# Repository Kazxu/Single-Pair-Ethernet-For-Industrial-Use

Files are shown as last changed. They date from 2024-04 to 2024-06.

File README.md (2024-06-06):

# Single Pair Ethernet For Industrial Use

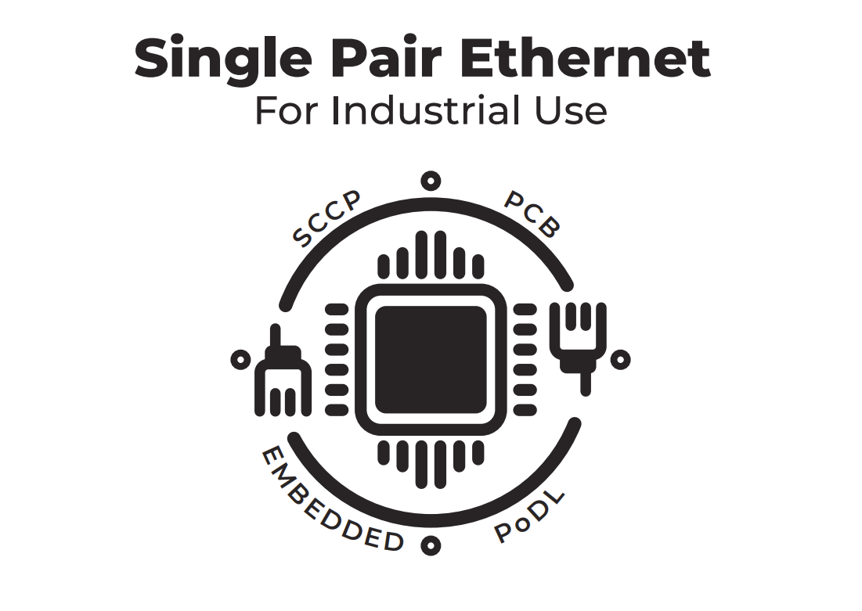
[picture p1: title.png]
ADIN1110_Title


## KICAD
KICAD PCB design files for the LTC4296-1 PSE prototype and LTC9111 PD prototype.

## SCCP 

SCCP_2 uses SPI to communicate with the LTC4296-1 prototype. 

See program print for features. 

SCCP classification between LTC4296-1 and LTC9111 can be performed as well.

## ADIN1110 - Development with STM32Cube IDE.

MCU Firmware : STM32L4xx - https://github.com/STMicroelectronics/STM32CubeL4 

LL DRIVERS : ADIN1110 Support files by Analog Devices.

TCP/IP : LWIP 2.1.2 & Callback API from LWIP. 

Serial Monitor : USART.c & USART.h, huart1.Init.BaudRate = 115200

ADC : INIT in Main.c & stm32l4xx_hal_msp.c

Client-side GUI CONCEPT PROTOTYPE - Python, Added as placeholder for showcase.

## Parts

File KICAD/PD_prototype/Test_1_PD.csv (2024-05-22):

# | Reference | Qty | Value | Footprint | Link Norge | Link JLCPCB | Link Andre steder
1 | C1 | 1 | 150nF | Capacitor_SMD:C_1206_3216Metric | https://no.farnell.com/tdk/cga5l2x7r2a154k160aa/cap-0-15-f-100v-10-x7r-1206/dp/2211081
2 | C2, C3 | 2 | 47nF | Capacitor_SMD:C_0805_2012Metric | https://no.farnell.com/kemet/c0805c473k1ractu/cap-0-047-f-100v-10-x7r-0805/dp/1907057
3 | CBULK1 | 1 | 47uF | 6.3x5.8 SMD tube | https://no.farnell.com/panasonic/eeefk1v470p/cap-47-f-35v-radial-smd-reel/dp/2254455
4 | CGATE1 | 1 | 22nF | Capacitor_SMD:C_0805_2012Metric | https://no.farnell.com/kemet/c0805x223k1ractu/cap-0-022-f-100v-10-x7r-0805/dp/1414043
5 | CSTBY1 | 1 | 2.2uF | Capacitor_SMD:C_0805_2012Metric | https://no.farnell.com/kemet/c0805c225k9ractu/cap-2-2-f-6-3v-10-x7r-0805/dp/2896867
6 | D1, D2 | 2 | PMEG10020AELR | Diode_SMD:Nexperia_CFP3_SOD-123W | https://no.farnell.com/nexperia/pmeg10020aelrx/schottky-rect-2a-100v-smd/dp/2498546?st=PMEG10020AELRX
7 | D3 | 1 | PTVS58VP1UTP | Diode_SMD:D_SOD-128 | https://no.farnell.com/nexperia/ptvs58vp1up-115/tvs-diodes/dp/4270914?st=PTVS58VP1UP,115
8 | IC1 | 1 | LTC9111RDE#PBF | KiCad:SON50P300X400X80-13N-D |  |  | https://no.mouser.com/ProductDetail/Analog-Devices/LTC9111RDEPBF?qs=rQFj71Wb1eUvOGbK5XL1vA%3D%3D
9 | J1 | 1 | Conn_01x04_Pin | Connector_PinHeader_2.54mm:PinHeader_1x04_P2.54mm_Vertical
10 | J2, J3 | 2 | Conn_01x06_Pin | Connector_PinHeader_2.54mm:PinHeader_1x06_P2.54mm_Vertical
11 | L2 | 1 | MSD7342-683MLC | footprints:MSD7342_COC | https://no.mouser.com/ProductDetail/Coilcraft/MSD7342-683MLC?qs=zCSbvcPd3pYlH%252BpyLo9nbw%3D%3D
12 | Q1 | 1 | PSMN075-100MSEX | footprints2:LFPAK33_SOT1210_NEX | https://no.farnell.com/nexperia/psmn075-100msex/mosfet-n-ch-100v-18a-lfpak33/dp/3440099?st=PSMN075-100MSEX
13 | Q2, Q3 | 2 | BSS123 | Package_TO_SOT_SMD:SOT-23 | https://no.farnell.com/onsemi/bss123/mosfet-n-100v-sot-23/dp/9845321?st=BSS123
14 | Q4, Q5 | 2 | BUK9M120-100EX | Package_TO_SOT_SMD:LFPAK33 | https://no.farnell.com/nexperia/buk9m120-100ex/mosfet-n-ch-aec-q101-11-5a-100v/dp/2760379?st=BUK9M120-100EX
15 | R1 | 1 | 40, 1/4 | Resistor_SMD:R_1206_3225Metric | https://no.farnell.com/yageo/rc1206fr-0743rl/res-43r-1-0-25w-1206-thick-film/dp/3496243
16 | R2 | 1 | 100 | Resistor_SMD:R_1206_3216Metric | https://no.farnell.com/vishay/crcw1206100rfkea/res-100r-1-0-25w-1206-thick-film/dp/1469977
17 | R3, R4, RBULK1 | 3 | 3.3, 1/4 | Resistor_SMD:R_1206_3216Metric | https://no.farnell.com/tt-electronics-welwyn/asc1206-3r3ft5/res-3r3-1-0-25w-1206-thick-film/dp/2078985
18 | RGATE1 | 1 | 10k | Resistor_SMD:R_1206_3216Metric | https://no.farnell.com/yageo/rc1206jr-0710kl/res-10k-5-0-25w-1206-thick-film/dp/9240640

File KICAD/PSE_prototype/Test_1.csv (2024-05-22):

# | Reference | Qty | Value | Footprint | DNP
1 | C1 | 1 | 1uF | Capacitor_SMD:C_0805_2012Metric | x
2 | C2 | 1 | 1nF | Capacitor_SMD:C_0805_2012Metric | x
3 | C3 | 1 | 0.1uF | Capacitor_SMD:C_0805_2012Metric | x
4 | C4 | 1 | 2.2u | Capacitor_SMD:C_0805_2012Metric | x
5 | C5, C7 | 2 | 2.2n | Capacitor_SMD:C_0805_2012Metric | x
6 | C6 | 1 | 0.47u | Capacitor_SMD:C_1206_3216Metric | x | 7
7 | D1 | 1 | SMAJ33A | Diode_SMD:D_SMA | x | 8
8 | J1 | 1 | Conn_01x04_Pin | Connector_PinHeader_2.54mm:PinHeader_1x04_P2.54mm_Vertical
9 | J2, J3 | 2 | Conn_01x02_Pin | Connector_PinHeader_2.54mm:PinHeader_1x02_P2.54mm_Vertical
10 | J4, J5, J6 | 3 | Conn_01x01_Pin | Connector_PinHeader_2.54mm:PinHeader_1x01_P2.54mm_Vertical
11 | J105, J106 | 2 | Conn_01x06_Pin | Connector_PinHeader_2.54mm:PinHeader_1x06_P2.54mm_Vertical
12 | JP1, JP2, JP3 | 3 | Jumper_3_Open | Connector_PinHeader_2.54mm:PinHeader_1x03_P2.54mm_Vertical
13 | L1 | 1 | MSD7342-683MLC | footprints:MSD7342_COC | x | 9
14 | Q1 | 1 | BUK7M45-40EX | Package_TO_SOT_SMD:LFPAK33 | x
15 | Q2, Q3 | 2 | BSS123 | Package_TO_SOT_SMD:SOT-23 | x
16 | Q4 | 1 | MMBTA06 | Package_TO_SOT_SMD:SOT-23 | x | 13
17 | R1 | 1 | 0.62 | Resistor_SMD:R_1206_3216Metric | x
18 | R2 | 1 | 50 | Resistor_SMD:R_0805_2012Metric | x
19 | R3 | 1 | 20 | Resistor_SMD:R_0805_2012Metric | x
20 | R4 | 1 | 10k | Resistor_SMD:R_0805_2012Metric | x
21 | R5, R8, R11 | 3 | 5k | Resistor_SMD:R_0805_2012Metric | x
22 | R6, R9 | 2 | 5 | Resistor_SMD:R_0805_2012Metric | x
23 | R7 | 1 | 24.3k | Resistor_SMD:R_0805_2012Metric | x
24 | R10 | 1 | 50k | Resistor_SMD:R_0805_2012Metric | x | 24
25 | U1 | 1 | ~ | Package_DFN_QFN:QFN-48-1EP_7x7mm_P0.5mm_EP5.3x5.3mm | x
26 | U2 | 1 | MOUDLE-SEEEDUINO-XIAO | XIAO_PCB:MOUDLE14P-2.54-21X17.8MM | x | 26

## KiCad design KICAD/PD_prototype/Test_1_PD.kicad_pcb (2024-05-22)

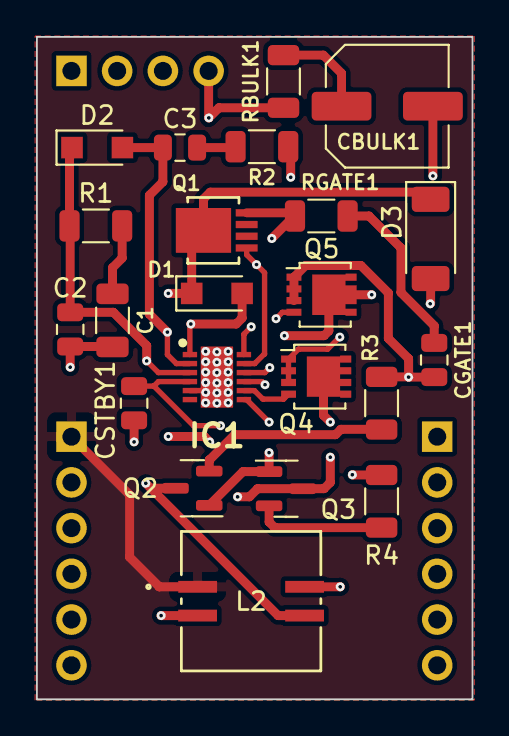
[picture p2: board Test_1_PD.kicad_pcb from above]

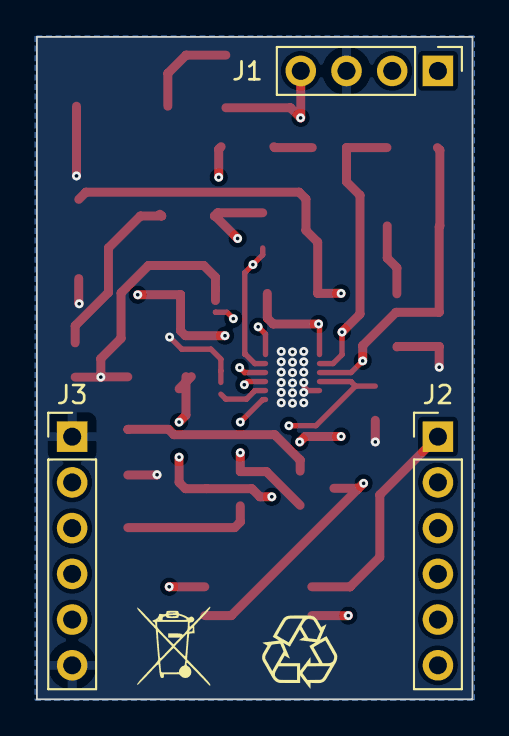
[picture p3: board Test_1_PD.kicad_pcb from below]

Board: 4 copper layers, 24.2 x 36.8 mm, 25 parts (3 on the bottom side), 18 nets.

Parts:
C1: 150nF; C_1206_3216Metric
C2, C3: 47nF; C_0805_2012Metric
CBULK1: 47uF; C_Elec_6.3x7.7
CGATE1: 22nF; C_0805_2012Metric
CSTBY1: 2.2uF; C_0805_2012Metric
D1, D2: PMEG10020AELR; Nexperia_CFP3_SOD-123W
D3: D_Zener; D_SOD-128
IC1: LTC9111RDE#PBF; SON50P300X400X80-13N-D
J1: Conn_01x04_Pin; PinHeader_1x04_P2.54mm_Vertical
J2, J3: Conn_01x06_Pin; PinHeader_1x06_P2.54mm_Vertical
L2: MSD7342-683MLC; MSD7342_COC
Q1: PSMN075-100MSEX; LFPAK33_SOT1210_NEX
Q2, Q3: BSS123; SOT-23
Q4, Q5: BUK9M120-100EX; LFPAK33
R1: 40, 1/4; R_1206_3216Metric
R2: 100; R_1206_3216Metric
R3, R4: 3.3, 1/4; R_1206_3216Metric
RBULK1: 3.3, 1/4; R_1206_3216Metric
RGATE1: 10k; R_1206_3216Metric

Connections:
/PODL+: J2.1, L2.1
/PODL-: J2.6, L2.4
GND: C1.2, C2.2, CBULK1.2, CGATE1.2, CSTBY1.2, D3.2 (A), IC1.5 (CLASSV), IC1.13 (GND), J1.3, J3.1, J3.6, Q4.1 (S), Q4.2 (S), Q4.3 (S), Q5.1 (S), Q5.2 (S), Q5.3 (S), R3.2, R4.2
unnamed: C1.1, R1.2
unnamed: C3.1, R2.2
unnamed: CBULK1.1, RBULK1.2
unnamed: CGATE1.1, RGATE1.2
unnamed: D1.2 (A), IC1.1 (SNS1), L2.3, Q2.3 (D), Q5.5 (D), R2.1
unnamed: C2.1, D1.1 (K), D2.1 (K), D3.1 (K), IC1.3 (IN), Q1.5 (D), R1.1
unnamed: C3.2, D2.2 (A), IC1.2 (SNS2), L2.2, Q3.3 (D), Q4.5 (D)
unnamed: CSTBY1.1, IC1.4 (STBY), IC1.10 (CLASSC)
unnamed: IC1.12 (GATE), Q1.4 (G), RGATE1.1
unnamed: IC1.9 (LGATE1), Q5.4 (G)
unnamed: IC1.8 (LGATE2), Q4.4 (G)
unnamed: IC1.11 (OUT), J1.4, Q1.1 (S), RBULK1.1
unnamed: IC1.7 (SCCP), Q2.1 (G), Q3.1 (G)
unnamed: Q2.2 (S), R3.1
unnamed: Q3.2 (S), R4.1

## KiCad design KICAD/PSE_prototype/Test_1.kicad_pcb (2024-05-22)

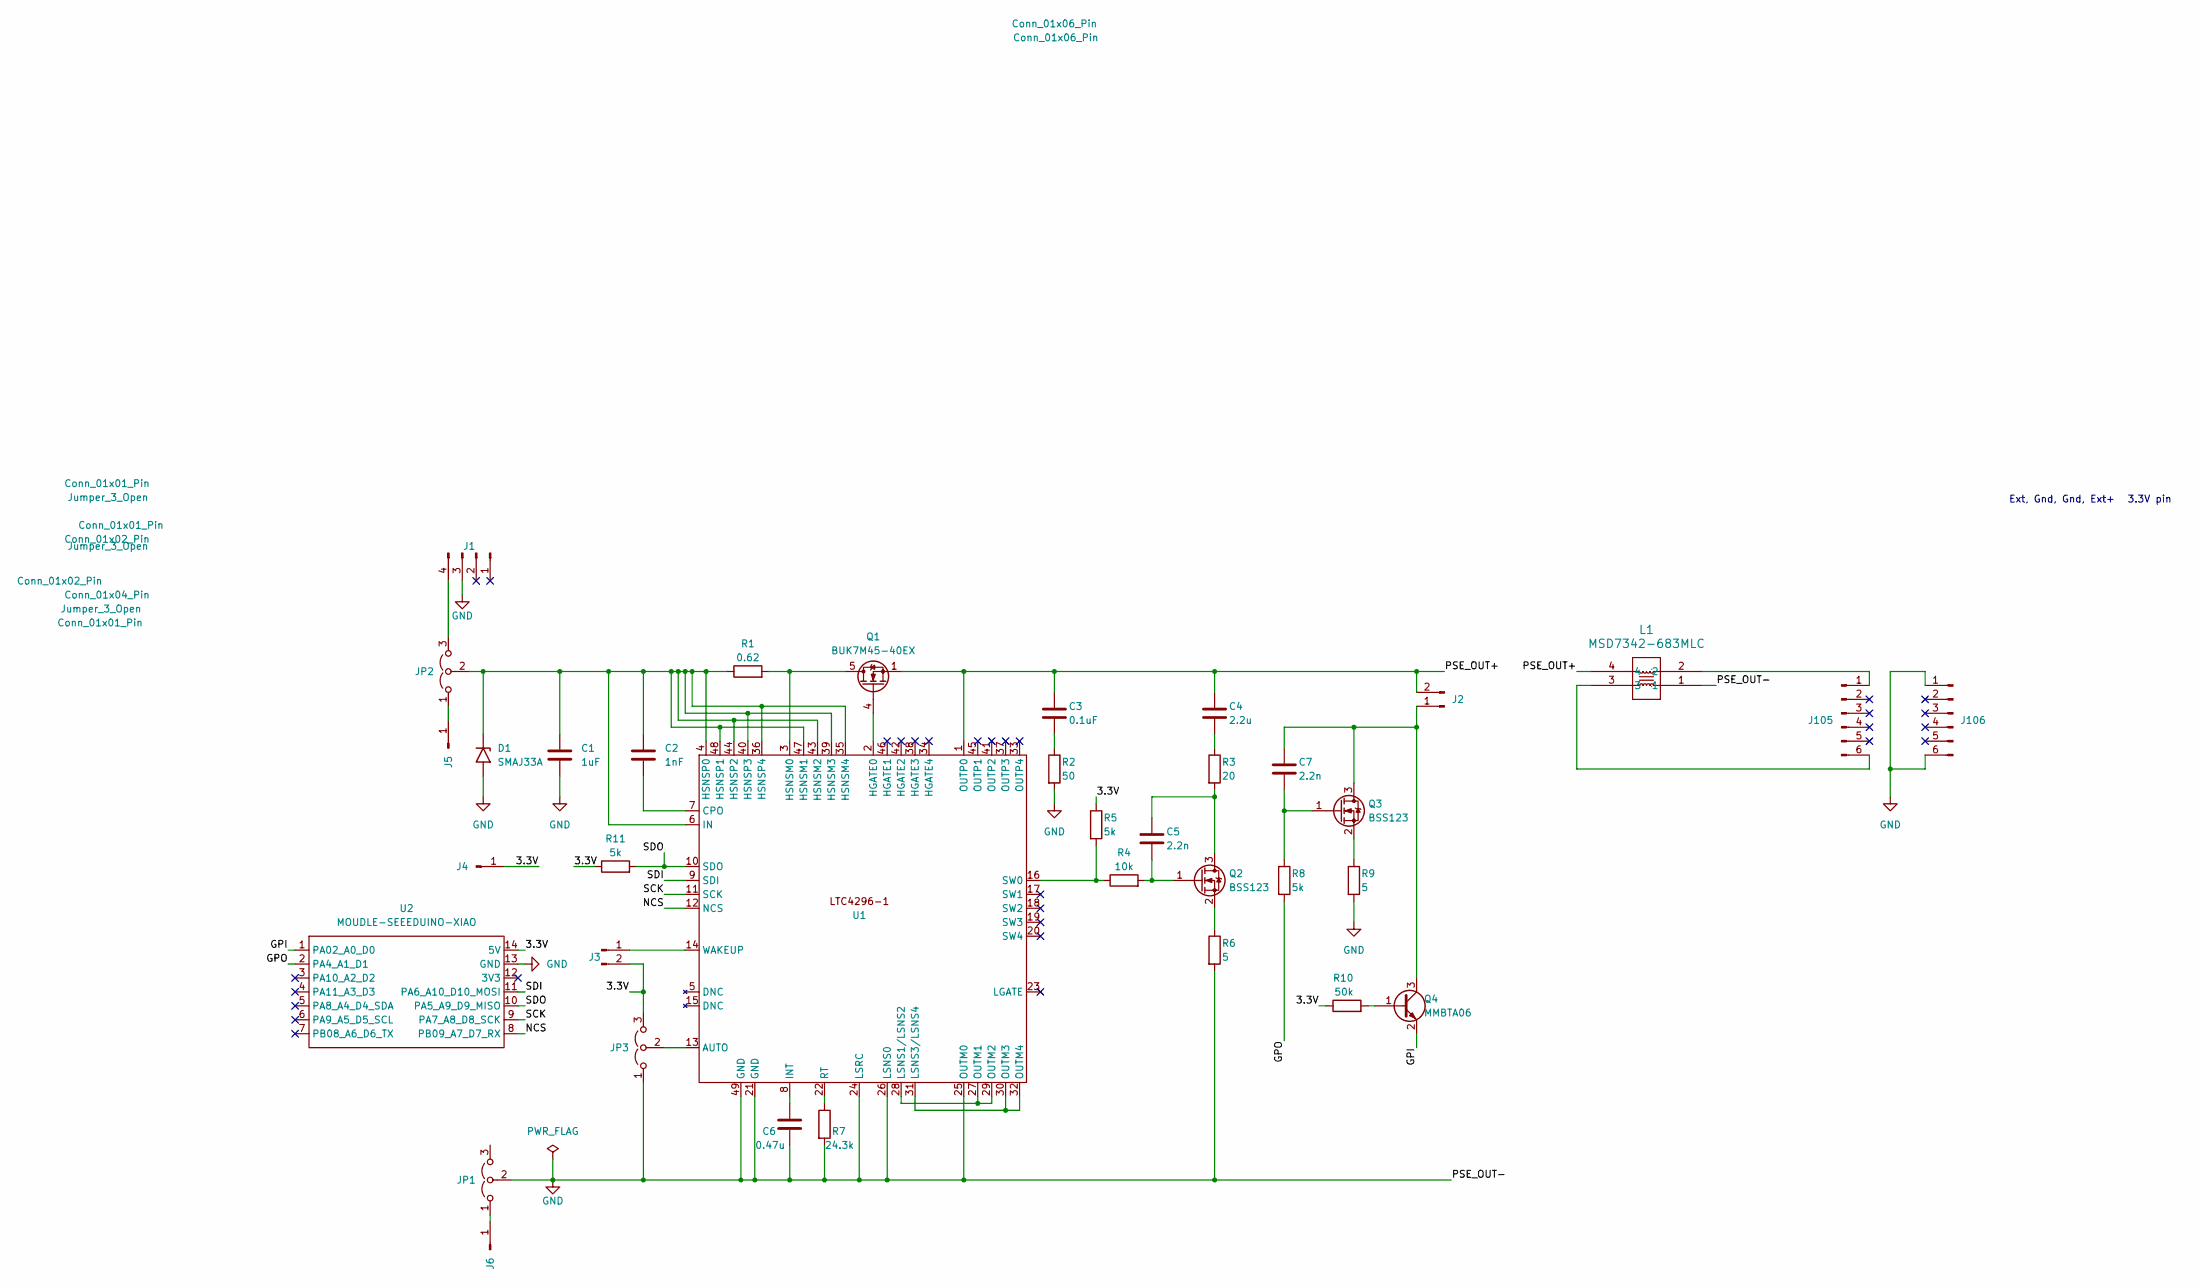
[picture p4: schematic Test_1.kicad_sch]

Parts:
C1: 1uF; C_0805_2012Metric
C2: 1nF; C_0805_2012Metric
C3: 0.1uF; C_0805_2012Metric
C4: 2.2u; C_0805_2012Metric
C5, C7: 2.2n; C_0805_2012Metric
C6: 0.47u; C_1206_3216Metric
D1: SMAJ33A; D_SMA
J1: Conn_01x04_Pin; PinHeader_1x04_P2.54mm_Vertical
J2, J3: Conn_01x02_Pin; PinHeader_1x02_P2.54mm_Vertical
J4, J5, J6: Conn_01x01_Pin; PinHeader_1x01_P2.54mm_Vertical
J105, J106: Conn_01x06_Pin; PinHeader_1x06_P2.54mm_Vertical
JP1, JP2, JP3: Jumper_3_Open; PinHeader_1x03_P2.54mm_Vertical
L1: MSD7342-683MLC; MSD7342_COC
Q1: BUK7M45-40EX; LFPAK33
Q2, Q3: BSS123; SOT-23
Q4: MMBTA06; SOT-23
R1: 0.62; R_1206_3216Metric
R2: 50; R_0603_1608Metric
R3: 20; R_0805_2012Metric
R4: 10k; R_0805_2012Metric
R5, R8, R11: 5k; R_0805_2012Metric
R6, R9: 5; R_0805_2012Metric
R7: 24.3k; R_0805_2012Metric
R10: 50k; R_0805_2012Metric
U1: QFN-48-1EP_7x7mm_P0.5mm_EP5.3x5.3mm
U2: MOUDLE-SEEEDUINO-XIAO; MOUDLE14P-2.54-21X17.8MM

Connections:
/3.3V: J3.2, J4.1, JP3.3 (B), R5.1, R10.1, R11.1, U2.14 (5V)
/OUT+: C3.1, C4.1, J2.2, L1.4, Q1.1 (S), Q1.2 (S), Q1.3 (S), U1.1 (OUTP0)
GND: C1.2, C6.2, D1.2 (A2), J1.3, J106.1, J106.6, JP1.2 (C), JP1.3 (B), JP3.1 (A), L1.1, R2.2, R6.2, R7.2, R9.2, U1.21 (GND), U1.24 (LSRC), U1.25 (OUTM0), U1.26 (LSNS0), U1.49 (GND), U2.13 (GND)
unnamed: C3.2, R2.1
unnamed: C4.2, R3.1
unnamed: C1.1, C2.1, D1.1 (A1), JP2.2 (C), R1.1, U1.4 (HSNSP0), U1.6 (IN), U1.35 (HSNSM4), U1.36 (HSNSP4), U1.39 (HSNSM3), U1.40 (HSNSP3), U1.43 (HSNSM2), U1.44 (HSNSP2), U1.47 (HSNSM1), U1.48 (HSNSP1)
unnamed: J1.4, JP2.3 (B)
unnamed: C7.1, J2.1, Q3.3 (D), Q4.3 (C)
unnamed: J3.1, U1.14 (WAKEUP)
unnamed: J5.1, JP2.1 (A)
unnamed: J6.1, JP1.1 (A)
unnamed: J105.1, L1.2
unnamed: J105.6, L1.3
unnamed: JP3.2 (C), U1.13 (AUTO)
unnamed: Q1.5 (D), R1.2, U1.3 (HSNSM0)
unnamed: Q1.4 (G), U1.2 (HGATE0)
unnamed: C5.1, Q2.3 (D), R3.2
unnamed: C5.2, Q2.1 (G), R4.2
unnamed: Q2.2 (S), R6.1
unnamed: C7.2, Q3.1 (G), R8.1
unnamed: Q3.2 (S), R9.1
unnamed: Q4.1 (B), R10.2
unnamed: Q4.2 (E), U2.1 (PA02_A0_D0)
unnamed: C2.2, U1.7 (CPO)
unnamed: C6.1, U1.8 (INT)
unnamed: U1.27 (OUTM1), U1.28 (LSNS1/LSNS2), U1.29 (OUTM2)
unnamed: U1.30 (OUTM3), U1.31 (LSNS3/LSNS4), U1.32 (OUTM4)
unnamed: U1.12 (NCS), U2.8 (PB09_A7_D7_RX)
unnamed: R7.1, U1.22 (RT)
unnamed: U1.11 (SCK), U2.9 (PA7_A8_D8_SCK)
unnamed: U1.9 (SDI), U2.11 (PA6_A10_D10_MOSI)
unnamed: R11.2, U1.10 (SDO), U2.10 (PA5_A9_D9_MISO)
unnamed: R4.1, R5.2, U1.16 (SW0)
unnamed: R8.2, U2.2 (PA4_A1_D1)

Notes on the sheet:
Ext, Gnd, Gnd, Ext+
3.3V pin

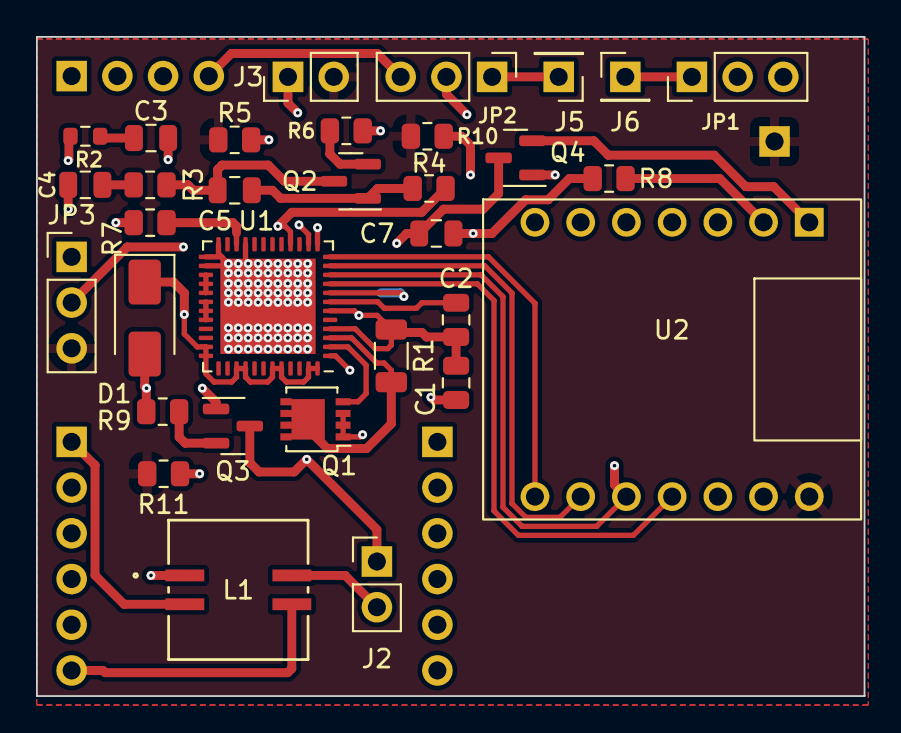
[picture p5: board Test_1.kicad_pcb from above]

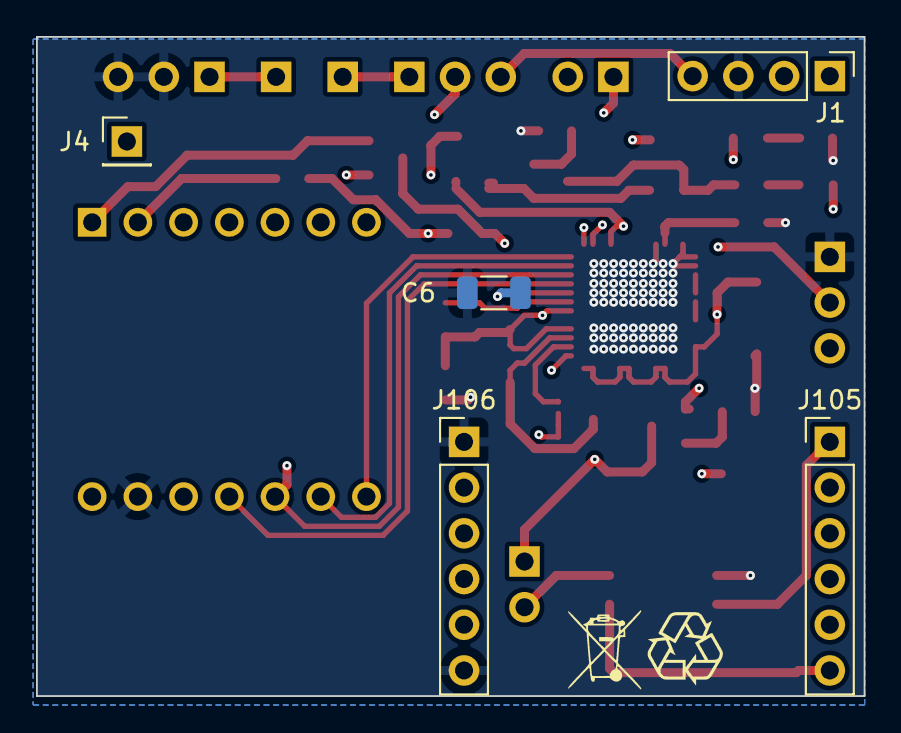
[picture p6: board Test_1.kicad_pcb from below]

Board: 4 copper layers, 46.0 x 36.6 mm, 37 parts (5 on the bottom side), 34 nets.

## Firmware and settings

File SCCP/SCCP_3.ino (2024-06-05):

#include <SPI.h>
#include <math.h>
//#include <iostream>
//#include <bits/stdc++.h>
#define VSPI_MISO   MISO 
#define VSPI_MOSI   MOSI
#define VSPI_SCLK   SCK
#define VSPI_SS     SS
#define GPIO1 D1
#define GPIO0 D0
#define LED_BUILTIN D2
static const int NCC[8] = {0,0,1,1,0,0,1,1}; //broadcast adress !0xCC
static const int NAA[8] = {0,1,0,1,0,1,0,1}; //scratchpad command for read !0xAA
int powerClass[8];
static const int spiClk = 1000000;           //1 MHz clock frequency for LTC4296-1
static const int t_w1l = 300;                //GPO HIGH
static const int t_w0l = 2000;               //writeslot
static const int t_w2l = t_w0l-t_w1l;        
static const int t_charge = 500;      
static const int t_write1 = t_w2l+t_charge;
static const int t_read = 2350;
bool SCCP_done = false;
bool power_on = false;
int MVFS = 0;
int c;
char cBuffer[128];
int cIndex = 0;
int i;
int j = 0;
uint16_t ADC_read = 0;
double Is = 0;
float dec = 0;
SPIClass * spi = NULL; //initializes SPIClass pointer
void setup() 
{
  delay(10);
  pinMode(GPIO1, OUTPUT);
  pinMode(GPIO0, INPUT);
  spi = new SPIClass(SPI); //creating the SPIClass object
  spi->begin(VSPI_SCLK, VSPI_MISO, VSPI_MOSI, VSPI_SS); //assigning SPI pins to class
  pinMode(spi->pinSS(), OUTPUT); //setting the chip-select pin
  Serial.begin(115200);
  while ( !Serial ) {
    digitalWrite(LED_BUILTIN, HIGH);  // turn the LED on (HIGH is the voltage level)
    delay(500);                       // wait for a second
    digitalWrite(LED_BUILTIN, LOW);   // turn the LED off by making the voltage LOW
    delay(500);    
  }
  digitalWrite(GPIO1, LOW);
  Serial.println("Initilized");
  Serial.println("Write to SPI using commands below: ");
  Serial.println("a : Global config.... ");
  Serial.println("b : Port 0 statuses..... ");
  Serial.println("c : Port to idle..... ");
  Serial.println("d : Force power-good..... ");
  Serial.println("e : Reset P0CFG0.... ");
  Serial.println("f : Set ports to searcing.... ");
  Serial.println("g : SCCP classification.... ");
  Serial.println("SCCP is ready.... ");
}
void loop() 
{
  //digitalWrite(GPIO1, LOW); //assert line HIGH between operations
  if (Serial.available()) 
  {
    c = Serial.read();
    //cBuffer[cIndex] = c;
    //Serial.println(c);
    if (c == 0x61) //if letter is a
    {
      Serial.println("a : Global config.....");
      spiWrite2(spi, 0x08, 0x00, 0x05, 0x0005); //write enable
      delay(1);
      spiWrite2(spi, 0x09, 0x00, 0x3D, 0x003D); //making lowfaults
      delay(1);
      spiWrite2(spi, 0x14, 0x00, 0x0C, 0x000C); //disable detection timer
      delay(1);
      spiWrite2(spi, 0x13, 0x00, 0x03, 0x0002); //disabled port
      delay(1);
      Serial.print("P0CG0 status: ");
      Serial.println(spiRead(spi, 0x13), HEX); //disabled to idle
      delay(1);
      Serial.print("P0ST status: ");
      Serial.println(spiRead(spi, 0x12), HEX);
      delay(1);
      Serial.print("P0EV status: ");
      Serial.println(spiRead(spi, 0x10), HEX);
      delay(1);
      Serial.println("");
    }
        if (c == 0x62) //if letter is b
    {
      Serial.println("b : Reading port 0.....");
      Serial.print("P0CG0 status: ");
      Serial.println(spiRead(spi, 0x13), HEX);
      delay(1);
      Serial.print("P0EV status: ");
      Serial.println(spiRead(spi, 0x10), HEX);
      delay(1);
      Serial.print("P0ST status: ");
      Serial.println(spiRead(spi, 0x12), HEX);
      delay(1);
      Serial.print("P0CFG0 status: ");
      Serial.println(spiRead(spi, 0x13), HEX);
      delay(1);
      Serial.print("P0CFG1 status: ");
      Serial.println(spiRead(spi, 0x14), HEX);
      delay(1);
      Serial.print("P0ADCDAT status: ");
      Serial.println(spiRead(spi, 0x16), HEX); // husk HEX
      delay(1);
      Serial.print("GADCDAT status: ");
      Serial.println(spiRead(spi, 0x0B), HEX);
      delay(1);
      Serial.print("P0ADCCFG status: ");
      Serial.println(spiRead(spi, 0x15), HEX);
      delay(1);
      Serial.print("P0ADCDAT status DEC: ");
      Serial.println(spiRead(spi, 0x16), DEC);
      delay(1);
      Serial.println("");
    }
    if (c == 0x63) //if letter is c
    {
      delay(1);
      Serial.println("c : Idle state set.....");
      spiWrite2(spi, 0x13, 0x00, 0x03, 0x0001 | 0x0002); //disabled to idle
      delay(1);
      Serial.print("reading P0CG0 regiser.... ");
      Serial.println(spiRead(spi, 0x13), HEX); //disabled to idle
      delay(1);
      Serial.print("P0EV status: ");
      Serial.println(spiRead(spi, 0x10), HEX);
      delay(1);
      Serial.print("P0ST status: ");
      Serial.println(spiRead(spi, 0x12), HEX);
      delay(1);
      Serial.print("P0CFG0 status: ");
      Serial.println(spiRead(spi, 0x13), HEX);
      delay(1);
      Serial.println("");
    }
    if (c == 0x64) //if letter is d
    {
      delay(1);
      Serial.println("d : Force power on.....");
      spiWrite2(spi, 0x13, 0x88, 0x27, 0x8827);
      delay(1);
      spiWrite2(spi, 0x14, 0x00, 0x0D, 0x000D); //write sim power good bit
      delay(1);
      Serial.print("P0EV status: ");
      Serial.println(spiRead(spi, 0x10), HEX);
      delay(1);
      Serial.print("P0ST status, 3012 if power-good: ");
      Serial.println(spiRead(spi, 0x12), HEX);
      delay(1);
      Serial.print("Write successful = 0x : ");
      Serial.println(spiRead(spi, 0x13), HEX);
      delay(1);
      power_on = true;
      Serial.println("");
    }
    if (c == 0x65) //if letter is e
    {
      Serial.println("e : Reset.... ");
      spiWrite2(spi, 0x13, 0x00, 0x02, 0x0002);
      delay(1);
      spiWrite2(spi, 0x14, 0x00, 0x0C, 0x000C); //write sim power good bit
      delay(1);
      power_on = false;
    //cIndex++;
    }
    if (c == 0x66) //if letter is f
    {
      delay(1);
      Serial.println("f : Ports are searching.....");
      spiWrite2(spi, 0x13, 0xA8, 0x27, 0xA827);
      delay(1);
      spiWrite2(spi, 0x14, 0x00, 0x0C, 0x000C); //write sim power good bit
      delay(1);
      Serial.print("P0EV status: ");
      Serial.println(spiRead(spi, 0x10), HEX);
      delay(1);
      Serial.print("P0ST status, 3012 if power-good: ");
      Serial.println(spiRead(spi, 0x12), HEX);
      delay(1);
      Serial.print("Write successful = 0x : ");
      Serial.println(spiRead(spi, 0x13), HEX);
      delay(1);
      Serial.println("");
    //cIndex++;
    }
    if (c == 0x67)  //trigger if g
    {
      Serial.println("g : SCCP test......");
      init(); //starter reset og sjekker om SCCP svarer med å trekke linja lav
      write_CC_AA(); //sender !0xCC og !0xAA, skal kun utføres når init() får riktig respons, men har ikke implementert det enda
      read_plot();
      Serial.print("\n");
    }
    if (c == 0x68)  //trigger if h, SCCP program
    {
      Serial.println("h : SCCP initiated.....");
      init(); 
      write_CC_AA(); 
      read_plot();
      if(powerClass[0] == 0 & powerClass[1] == 1 & powerClass[2] == 0 & powerClass[3] == 0 & 
         powerClass[4] == 0 & powerClass[5] == 0 & powerClass[6] == 0 & powerClass[7] == 0)
      {
        Serial.println("SCCP classification successful: ");
        Serial.println("d : SCCP power on.....");
        spiWrite2(spi, 0x13, 0x88, 0x27, 0x8827);
        delay(1);
        spiWrite2(spi, 0x14, 0x00, 0x0D, 0x000D); //write sim power good bit
        delay(1);
        power_on = true;
      }
      else
      {
        Serial.println("SCCP classification unsuccessful: ");
        spiWrite2(spi, 0x13, 0x00, 0x02, 0x0002);
        delay(1);
        spiWrite2(spi, 0x14, 0x00, 0x0C, 0x000C); 
        delay(1);
        power_on = false;
      }
      }
      Serial.print("\n");
    }
  digitalWrite(GPIO1, LOW); 
  if (power_on == true)
  {
    delay(200);
    ADC_read = (spiRead(spi, 0x16));
    //Serial.println(ADC_read);
    dec = parse(ADC_read) - 12288;
    //Serial.println(dec);
    Is = ((dec-2048)/0.62)/10;
    Serial.println(Is);
    if (power_on == true & Is < 5)
    {
      Serial.println("MFVS fault.... ");
      spiWrite2(spi, 0x13, 0x00, 0x02, 0x0002);
      delay(1);
      spiWrite2(spi, 0x14, 0x00, 0x0C, 0x000C); //write sim power good bit
      delay(1);
      power_on = false;
    }
  }
  delay(200);
}
void init (void)
{
      delay(1);
      digitalWrite(GPIO1, HIGH); //skrur av linja i 9.3ms
      delayMicroseconds(9300); //reset init
      digitalWrite(GPIO1, LOW); //reset end
      delay(3);
      while(digitalRead(GPIO0) != 1) //interrupt funksjon, ikke optimal men fungerer til testingen. Sjekker når SCCP er ferdig med å sende
      {
      }
      Serial.println("SCCP pin pulls LOW.....");
}
void write_CC_AA (void)
{
  delayMicroseconds(500);
  //Write broadcast adress
  for (i=0; i<8; i++)
  {
    Serial.print(NCC[i]);
    if(NCC[i] == 1)
    {
      //HIGH write slot pulse
      digitalWrite(GPIO1, HIGH); 
      delayMicroseconds(t_w1l);
      digitalWrite(GPIO1, LOW); 
      delayMicroseconds(t_write1); 
    }
    else
    {
      //LOW write slot pulse
      digitalWrite(GPIO1, HIGH); 
      delayMicroseconds(t_w0l);
      digitalWrite(GPIO1, LOW);  
      delayMicroseconds(t_charge);
    }
  }
  Serial.println("");
  //Write scratchpad command
  for (i=0; i<8; i++)
  {
    Serial.print(NAA[i]);
    if(NAA[i] == 1)
    {
      //HIGH write slot pulse
      digitalWrite(GPIO1, HIGH); 
      delayMicroseconds(t_w1l);
      digitalWrite(GPIO1, LOW); 
      delayMicroseconds(t_write1); 
    }
    else
    {
      //LOW write slot pulse
      digitalWrite(GPIO1, HIGH); 
      delayMicroseconds(t_w0l);
      digitalWrite(GPIO1, LOW);  
      delayMicroseconds(t_charge);
    }
  }
  Serial.println("\n");
}
uint16_t spiRead(SPIClass *spi, byte rAdress)
{
  uint8_t rAdress1 = (rAdress << 1) | 0x01;
  uint8_t PECA = get_pec_byte(rAdress1, 0x41);
  uint16_t datain;
  uint8_t PECD;
  spi->beginTransaction(SPISettings(spiClk, MSBFIRST, SPI_MODE0));
  digitalWrite(spi->pinSS(), LOW);
  spi->transfer(rAdress1);
  spi->transfer(PECA);
  datain = spi->transfer16(0x0000);
  PECD = spi->transfer(0x00);
  digitalWrite(spi->pinSS(), HIGH);
  spi->endTransaction();
  return datain;
}
uint16_t spiWrite2(SPIClass *spi, byte rAdress, byte data1, byte data0, uint16_t data)
{
  uint8_t rAdress1 = (rAdress << 1) & ~0x01;
  uint8_t PECR = get_pec_byte(rAdress1, 0x41);
  uint8_t intermediate = get_pec_byte(data1, 0x41);
  uint8_t PECD = get_pec_byte(data0, intermediate);
  uint16_t dataOut;
  spi->beginTransaction(SPISettings(spiClk, MSBFIRST, SPI_MODE0));
  digitalWrite(spi->pinSS(), LOW);
  spi->transfer(rAdress1);
  spi->transfer(PECR);
  spi->transfer16(data);
  spi->transfer(PECD);
  digitalWrite(spi->pinSS(), HIGH);
  spi->endTransaction();
  return dataOut;
}
uint16_t spiWrite(SPIClass *spi, byte rAdress, byte data1, byte data0, uint16_t data)
{
  uint8_t rAdress1 = (rAdress << 1) & ~0x01;
  uint8_t PECR = get_pec_byte(rAdress1, 0x41);
  uint8_t intermediate = get_pec_byte(data1, 0x41);
  uint8_t PECD = get_pec_byte(data0, intermediate);
  uint16_t dataOut;
  spi->beginTransaction(SPISettings(spiClk, MSBFIRST, SPI_MODE0));
  digitalWrite(spi->pinSS(), LOW);
  spi->transfer(rAdress1);
  spi->transfer(PECR);
  spi->transfer16(data);
  spi->transfer(PECD);
  digitalWrite(spi->pinSS(), HIGH);
  spi->endTransaction();
  return dataOut;
}
void read_plot(void)
{
  Serial.print("Response from LTC9111: ");
  for (i=0;i<8;i++)
  {
    digitalWrite(GPIO1, HIGH);
    delayMicroseconds(t_w1l);
    digitalWrite(GPIO1, LOW);
    delayMicroseconds(200);
    //Serial.print(digitalRead(GPIO0));
    powerClass[i] = digitalRead(GPIO0);
    Serial.print(powerClass[i]);
    delayMicroseconds(t_read-200);
  }
  Serial.println("");
}
uint8_t get_pec_byte(uint8_t data, uint8_t seed) //calculate PEC byte
{
 uint8_t pec = seed;
 uint8_t din, in0, in1, in2;
 int bit;
 for(bit=7; bit>=0; bit--)
 {
 din = (data>>bit) & 0x01;
 in0 = din ^ ( (pec>>7) & 0x01 );
 in1 = in0 ^ ( pec & 0x01);
 in2 = in0 ^ ( (pec>>1) & 0x01 );
 pec = (pec << 1);
 pec &= ~(0x07);
 pec = pec | in0 | (in1<<1) | (in2<<2);
 }
 return pec;
}
int parse(unsigned int n) 
{
    int decimalValue = 0;
    int base = 1; // Initialize base value to 1 (16^0)

    while (n) {
        int last_digit = n % 16;
        decimalValue += last_digit * base;
        base = base * 16;
        n = n / 16;
    }
    return decimalValue;
}

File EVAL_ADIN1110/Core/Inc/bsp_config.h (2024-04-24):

/*
 *---------------------------------------------------------------------------
 *
 * Copyright (c) 2020, 2021 Analog Devices, Inc. All Rights Reserved.
 * This software is proprietary to Analog Devices, Inc.
 * and its licensors.By using this software you agree to the terms of the
 * associated Analog Devices Software License Agreement.
 *
 *---------------------------------------------------------------------------
 */

#ifndef BSP_CONFIG_H
#define BSP_CONFIG_H



#if defined(EVAL_ADIN1110EBZ)
#define ETH_RESET_Pin GPIO_PIN_7
#define ETH_RESET_GPIO_Port GPIOC
#else
#define ETH_RESET_Pin GPIO_PIN_8
#define ETH_RESET_GPIO_Port GPIOB
#endif


#define ETH_SPI                 SPI2
#define ETH_SPI_IRQn            SPI2_IRQn
#define ETH_SPI_IRQ_HANDLER     SPI2_IRQHandler
#define ETH_SPI_CLK_ENABLE		__HAL_RCC_SPI2_CLK_ENABLE
#define ETH_SPI_CLK_DISABLE 	__HAL_RCC_SPI2_CLK_DISABLE

#define ETH_SPI_SS_Pin          GPIO_PIN_12
#define ETH_SPI_SS_GPIO_Port    GPIOB
#define ETH_SPI_MOSI_Pin        GPIO_PIN_15
#define ETH_SPI_MOSI_GPIO_Port  GPIOB
#define ETH_SPI_MOSI_AF         GPIO_AF5_SPI2
#if defined(USE_NUCLEO)
#define ETH_SPI_MISO_Pin        GPIO_PIN_2
#define ETH_SPI_MISO_GPIO_Port  GPIOC
#else
#define ETH_SPI_MISO_Pin        GPIO_PIN_14
#define ETH_SPI_MISO_GPIO_Port  GPIOB
#endif
#define ETH_SPI_MISO_AF         GPIO_AF5_SPI2
#define ETH_SPI_CLK_Pin         GPIO_PIN_13
#define ETH_SPI_CLK_GPIO_Port   GPIOB
#define ETH_SPI_CLK_AF          GPIO_AF5_SPI2


#define ETH_SPI_DMA_REQ_TX      DMA_REQUEST_SPI2_TX
#define ETH_SPI_DMA_REQ_RX      DMA_REQUEST_SPI2_RX

#if defined(EVAL_ADIN1110EBZ)
#define ETH_INT_N_Pin           GPIO_PIN_11
#define ETH_INT_N_GPIO_Port     GPIOB
#else
#define ETH_INT_N_Pin           GPIO_PIN_12
#define ETH_INT_N_GPIO_Port     GPIOA
#endif
#define ETH_INT_N_IRQn          EXTI15_10_IRQn
#define ETH_INT_N_IRQ_HANDLER   EXTI15_10_IRQHandler

#if defined(EVAL_ADIN1110EBZ)
#define BSP_LED1_PORT           GPIOC
#define BSP_LED1_PIN            GPIO_PIN_13
#define BSP_LED2_PORT           GPIOE
#define BSP_LED2_PIN            GPIO_PIN_2
#define BSP_LED3_PORT           GPIOE
#define BSP_LED3_PIN            GPIO_PIN_6
#define BSP_LED4_PORT           GPIOG
#define BSP_LED4_PIN            GPIO_PIN_15
#else
#define BSP_LED1_PORT           GPIOB
#define BSP_LED1_PIN            GPIO_PIN_6
#define BSP_LED2_PORT           GPIOE
#define BSP_LED2_PIN            GPIO_PIN_6
#define BSP_LED3_PORT           GPIOB
#define BSP_LED3_PIN            GPIO_PIN_11
#define BSP_LED4_PORT           GPIOE
#define BSP_LED4_PIN            GPIO_PIN_2
#define BSP_LED5_PORT           GPIOB
#define BSP_LED5_PIN            GPIO_PIN_10
#endif

#define ETH_GPIO_ENABLE         do { \
                                    __HAL_RCC_GPIOA_CLK_ENABLE(); \
                                    __HAL_RCC_GPIOB_CLK_ENABLE(); \
                                    __HAL_RCC_GPIOC_CLK_ENABLE(); \
                                    __HAL_RCC_GPIOD_CLK_ENABLE(); \
                                    __HAL_RCC_GPIOE_CLK_ENABLE(); \
                                    __HAL_RCC_GPIOF_CLK_ENABLE(); \
                                    __HAL_RCC_GPIOG_CLK_ENABLE(); \
                                    __HAL_RCC_GPIOH_CLK_ENABLE(); \
                                } while(0)

/* Assign one of the symbols defined below to configure SYSCLK/SCLK frequencies */
#define BSP_CLK_CFG             (BSP_CLK_CFG_96_24)

#define BSP_CLK_CFG_96_24       (0)
#define BSP_CLK_CFG_25_12P5     (1)
#define BSP_CLK_CFG_120_15      (2)
#define BSP_CLK_CFG_100_25      (3)
#define BSP_CLK_CFG_80_5        (4)
#define BSP_CLK_CFG_100_12P5    (5)

#if (BSP_CLK_CFG == BSP_CLK_CFG_96_24)

#define BSP_CLK_CFG_PLLN                (48)
#define BSP_CLK_CFG_PLLR                (RCC_PLLR_DIV2)
#define BSP_CLK_CFG_APB1CLKDIV          (RCC_HCLK_DIV2)
#define BSP_CLK_CFG_SPI_BAUDPRESCALER   (SPI_BAUDRATEPRESCALER_2)
#define BSP_CLK_CFG_FLASH_LATENCY       (FLASH_LATENCY_4)

#elif (BSP_CLK_CFG == BSP_CLK_CFG_25_12P5)

#define BSP_CLK_CFG_PLLN                (25)
#define BSP_CLK_CFG_PLLR                (RCC_PLLR_DIV4)
#define BSP_CLK_CFG_APB1CLKDIV          (RCC_HCLK_DIV1)
#define BSP_CLK_CFG_SPI_BAUDPRESCALER   (SPI_BAUDRATEPRESCALER_2)
#define BSP_CLK_CFG_FLASH_LATENCY       (FLASH_LATENCY_1)

#elif (BSP_CLK_CFG == BSP_CLK_CFG_120_15)

#define BSP_CLK_CFG_PLLN                (60)
#define BSP_CLK_CFG_PLLR                (RCC_PLLR_DIV2)
#define BSP_CLK_CFG_APB1CLKDIV          (RCC_HCLK_DIV4)
#define BSP_CLK_CFG_SPI_BAUDPRESCALER   (SPI_BAUDRATEPRESCALER_2)
#define BSP_CLK_CFG_FLASH_LATENCY       (FLASH_LATENCY_5)

#elif (BSP_CLK_CFG == BSP_CLK_CFG_100_25)

#define BSP_CLK_CFG_PLLN                (50)
#define BSP_CLK_CFG_PLLR                (RCC_PLLR_DIV2)
#define BSP_CLK_CFG_APB1CLKDIV          (RCC_HCLK_DIV2)
#define BSP_CLK_CFG_SPI_BAUDPRESCALER   (SPI_BAUDRATEPRESCALER_2)
#define BSP_CLK_CFG_FLASH_LATENCY       (FLASH_LATENCY_4)

#elif (BSP_CLK_CFG == BSP_CLK_CFG_80_5)
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

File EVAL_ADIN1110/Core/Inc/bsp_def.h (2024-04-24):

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

/* Define to prevent recursive inclusion -------------------------------------*/
#ifndef BSP_DEF_H
#define BSP_DEF_H

#ifdef __cplusplus
extern "C" {
#endif

/* Includes ------------------------------------------------------------------*/

/* Exported types ------------------------------------------------------------*/
/* Exported constants --------------------------------------------------------*/
/* Exported macro ------------------------------------------------------------*/
/* Exported functions prototypes ---------------------------------------------*/

#define EEPROM_CS_Pin             GPIO_PIN_4
#define EEPROM_CS_GPIO_Port       GPIOA
#define EEPROM_MISO_Pin           GPIO_PIN_7
#define EEPROM_MISO_GPIO_Port     GPIOA
#define EEPROM_SCK_Pin            GPIO_PIN_5
#define EEPROM_SCK_GPIO_Port      GPIOA
#define EEPROM_MISOA6_Pin         GPIO_PIN_6
#define EEPROM_MISOA6_GPIO_Port   GPIOA
#define CFG2_Pin                  GPIO_PIN_2
#define CFG2_GPIO_Port            GPIOB
#define CFG3_Pin                  GPIO_PIN_5
#define CFG3_GPIO_Port            GPIOB
#define AltSS_Pin                 GPIO_PIN_9
#define CFG0_Pin                  GPIO_PIN_0
#define CFG0_GPIO_Port            GPIOB
#define CFG1_Pin                  GPIO_PIN_1
#define CFG1_GPIO_Port            GPIOB
#ifdef __cplusplus
}
#endif

#endif /* BSP_DEF_H */

/************************ (C) COPYRIGHT STMicroelectronics *****END OF FILE****/

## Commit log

2024-05-14 Changed Global to stream data, ADC still no value
2024-05-20 Fixed Buffer to stream data through Serial Monitor, ADC still no value, buffer now shared through Echo server and Main
    [gpio.c]
2024-05-22 ADDED KICAD + changed README
    [Test_1-B_Cu.gbr, Test_1-B_Mask.gbr, Test_1-B_Paste.gbr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]
2024-05-24 ADC Implemented & FIXED, NON-Calibrated
    [adi_mac.c, adi_mac.h, adi_phy.c]
2024-05-27 CONCEPT PROTOTYPE GUI ADDED, TCP sends mA Value
2024-06-06 TCP heartbeat check for CLIENT SIDE PROTOTYPE

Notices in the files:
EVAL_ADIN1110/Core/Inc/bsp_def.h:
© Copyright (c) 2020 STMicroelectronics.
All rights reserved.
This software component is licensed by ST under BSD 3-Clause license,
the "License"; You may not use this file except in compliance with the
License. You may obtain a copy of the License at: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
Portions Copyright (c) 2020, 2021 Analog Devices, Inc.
